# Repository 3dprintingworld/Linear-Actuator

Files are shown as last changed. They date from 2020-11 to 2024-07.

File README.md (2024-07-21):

# Mostly Printed Linear Actuator Project

The goal of this project is to design a mostly printed bearing that can be used on a Mostly Printed 3D printer.

### Design Level #1
PTFE Inserted Bearing<br/>
This version uses PTFE Tube otherwise known as Bowden tube as a bearing surface.  It worked good in initial testing but failed quickly after adding a load to the bearing. <br/>
(obsoleted)<br/>
<br/>

### Design Level #2<br/>
Dovetail Guided Actuator<br/>
This version utilizes a nylon filament from Jabil with a low friction addative.<br/>
(current model)<br/>
<br/>
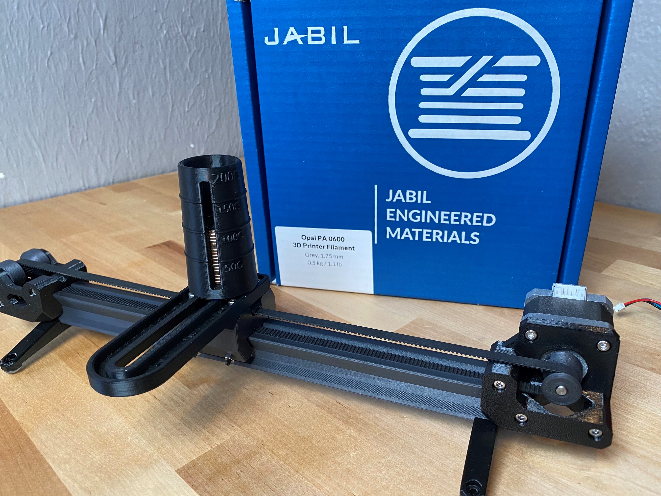
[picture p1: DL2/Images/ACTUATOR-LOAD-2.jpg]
P


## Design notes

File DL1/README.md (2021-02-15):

# Mostly printed Linear Actuator with PTFE bearing
Make a linear actuator with only a few purchased components and your 3D printer! Perfect for low load, low cycle applications. All you need is a 3D printer, stepper motor, bearing balls, fasteners, and PTFE bowden tubing.
<br/>
### Features:
PTFE inserted linear bearing<br/>
Rails can be bolted together for infinite travel lengths.<br/>
Printable TPU GT2 belt file included, prints in vase mode. It is also compatible with a standard GT2 6mm wide belt.<br/>
3D Printed idler pulley with integrated caged bearing balls.<br/>
<br/>
P
P
P
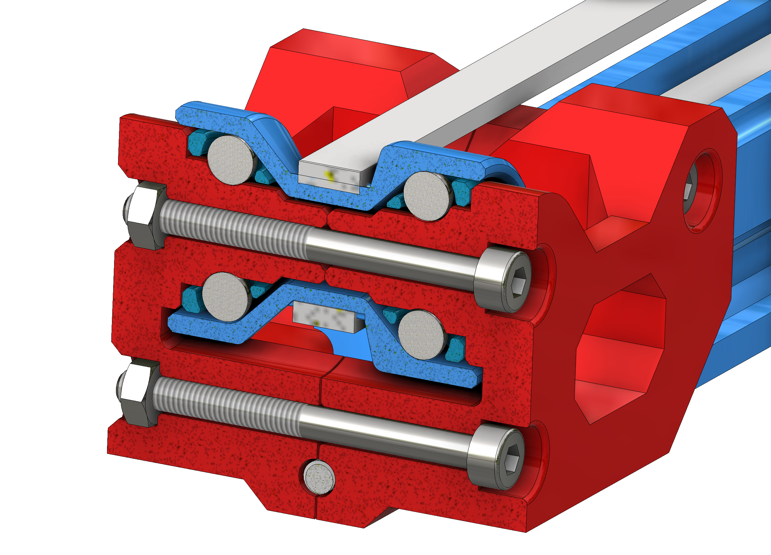
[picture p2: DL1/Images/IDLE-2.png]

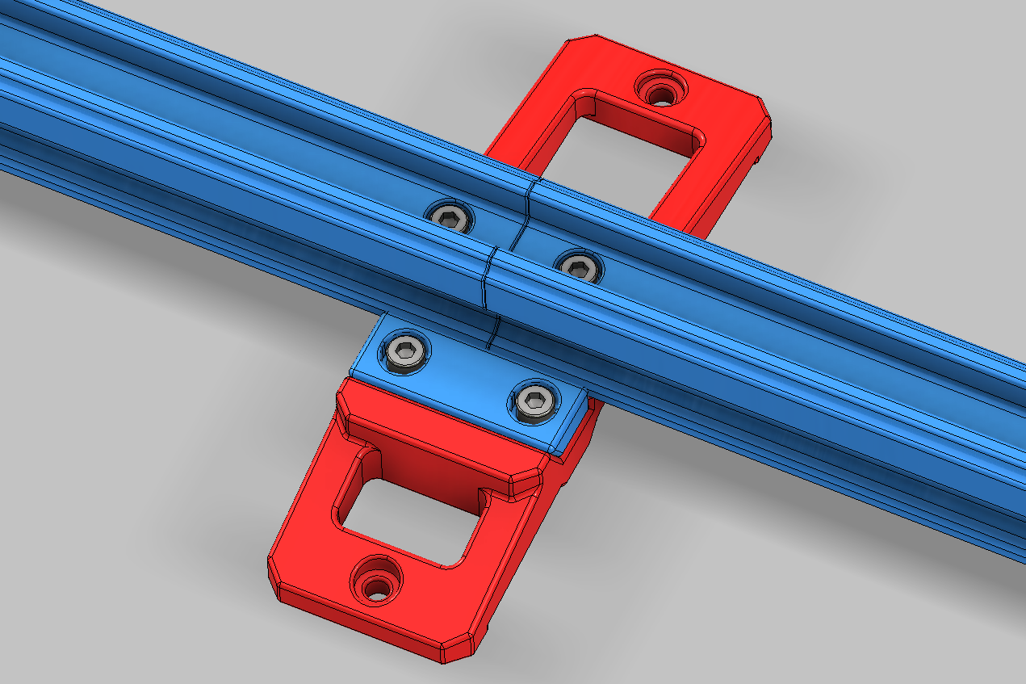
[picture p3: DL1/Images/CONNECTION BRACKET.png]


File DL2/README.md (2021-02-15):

# Mostly printed Linear Dovetail Actuator 
Make a linear actuator with only a few purchased components and your 3D printer! Perfect for low load, low cycle applications. All you need is a 3D printer, a stepper motor, bearing balls, fasteners, and PTFE bowden tubing.<br/>
### Features
This actuator is designed to use Jabil's Opal PA 0600 low friction nylon filament as bearing materail.<br/>
Printable TPU GT2 belt file included, prints in vase mode. It is also compatible with a standard GT2 6mm wide belt.<br/>
3D Printed idler pulley with integrated caged bearing balls.<br/>
<br/>
Note: Scale the parts that you print out of this filament up by 2%.<br/>
<br/>
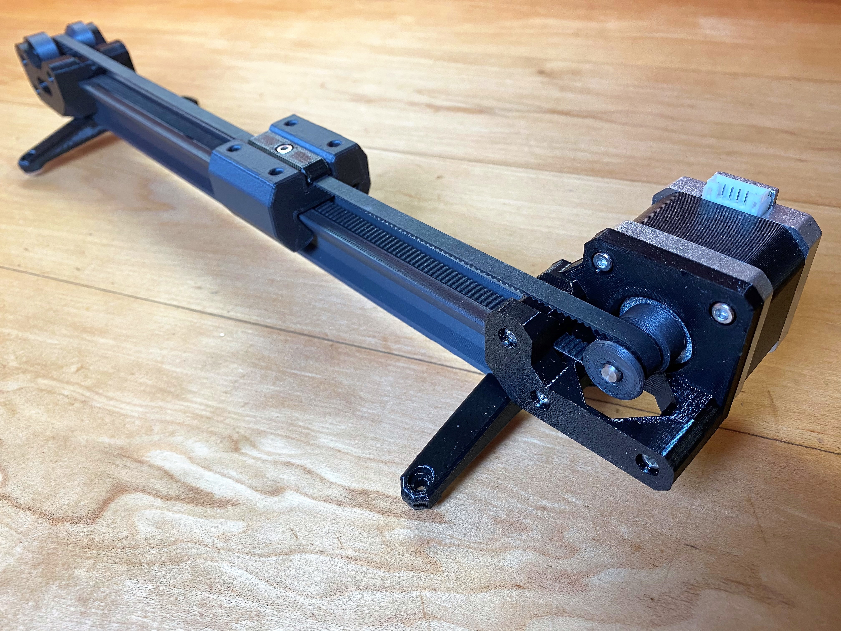
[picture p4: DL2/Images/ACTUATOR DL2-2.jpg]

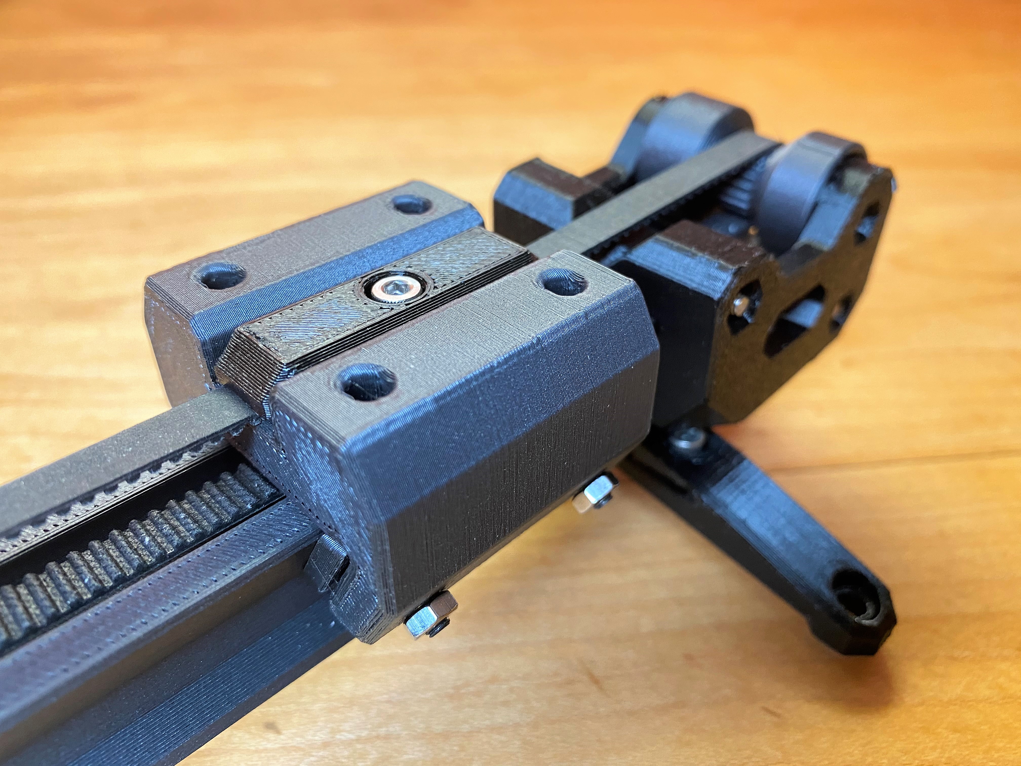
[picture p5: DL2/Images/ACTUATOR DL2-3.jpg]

P
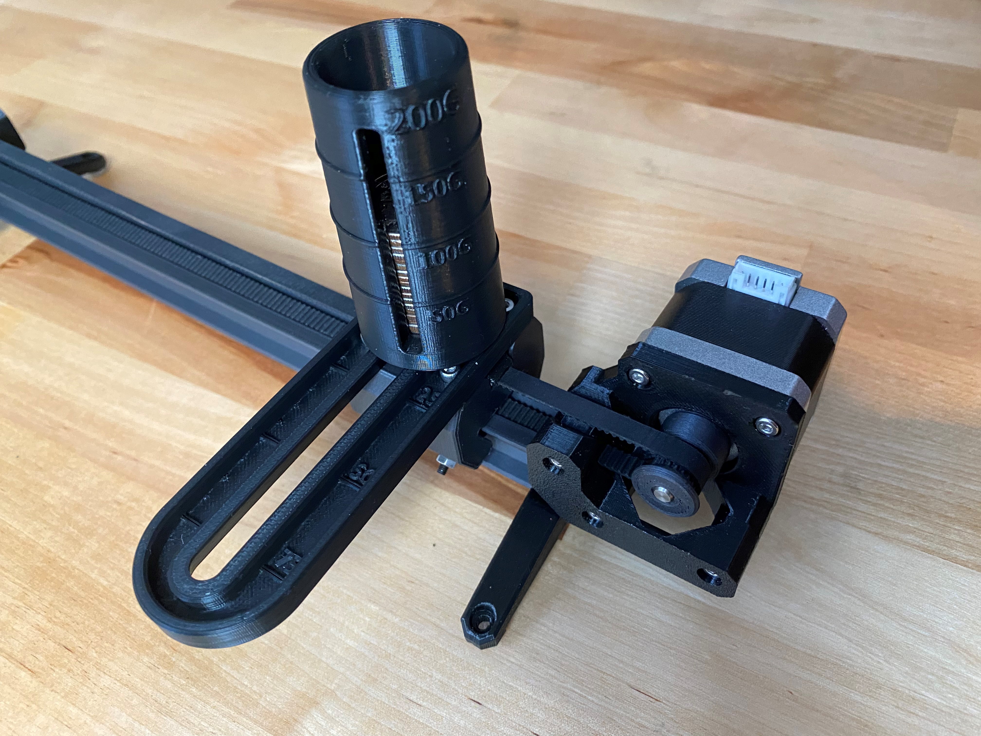
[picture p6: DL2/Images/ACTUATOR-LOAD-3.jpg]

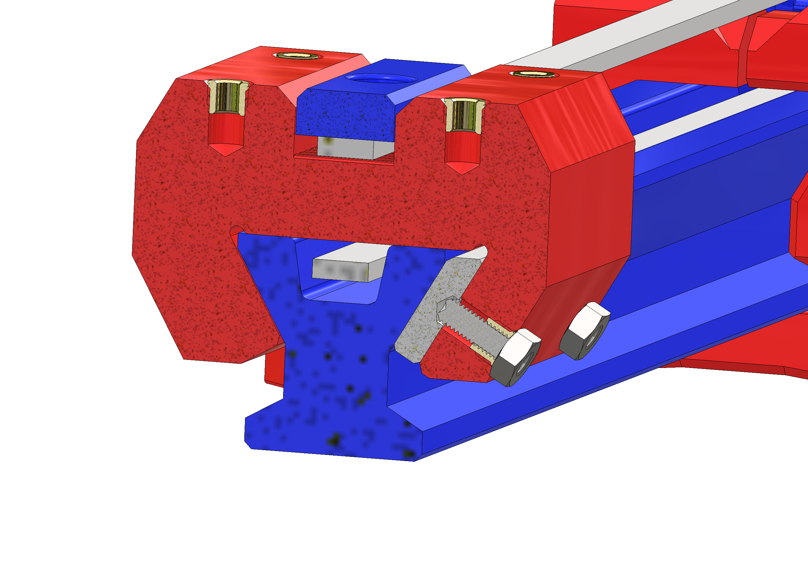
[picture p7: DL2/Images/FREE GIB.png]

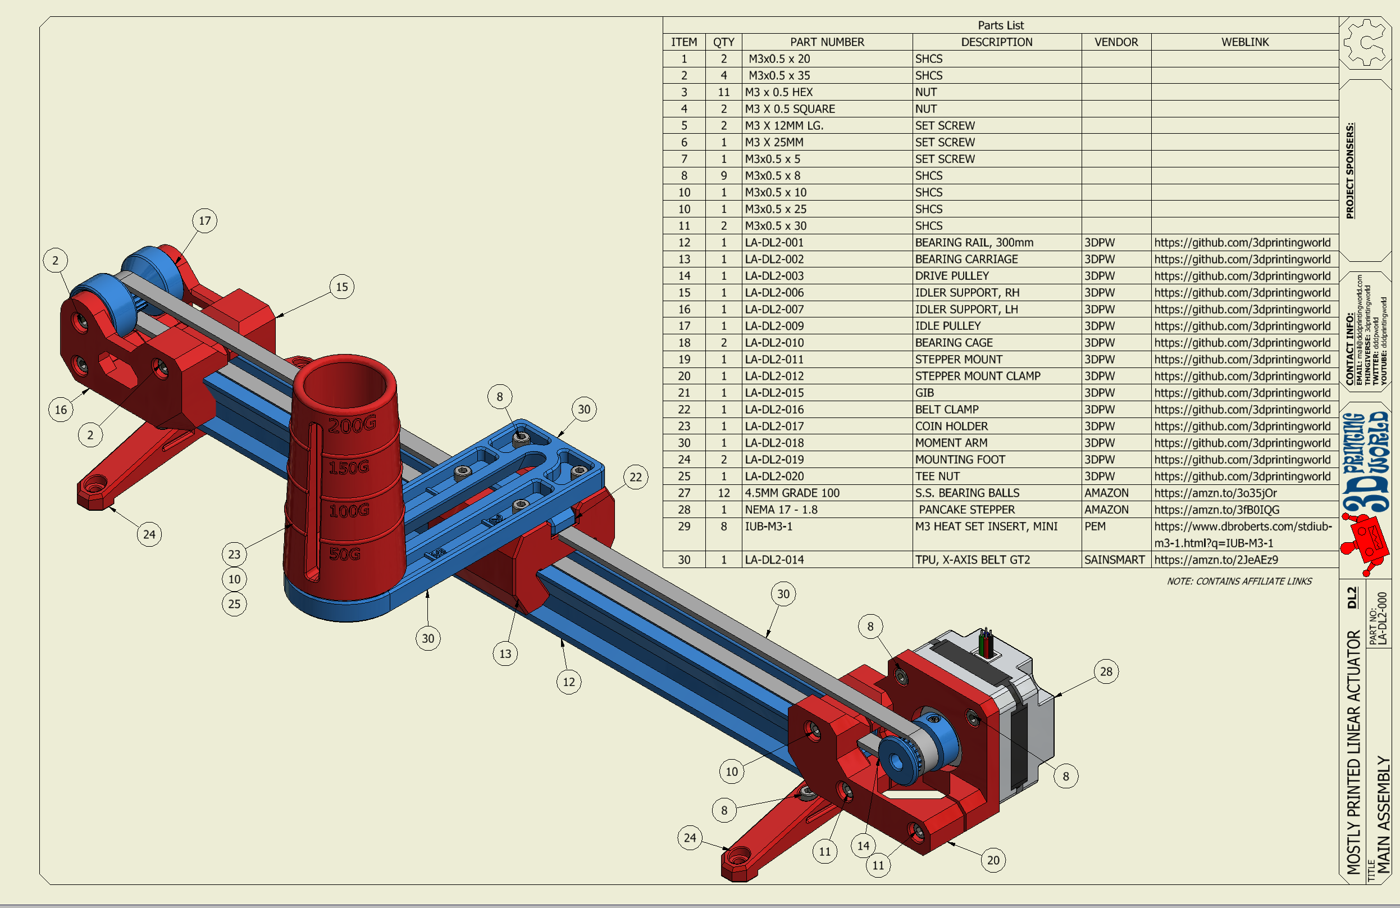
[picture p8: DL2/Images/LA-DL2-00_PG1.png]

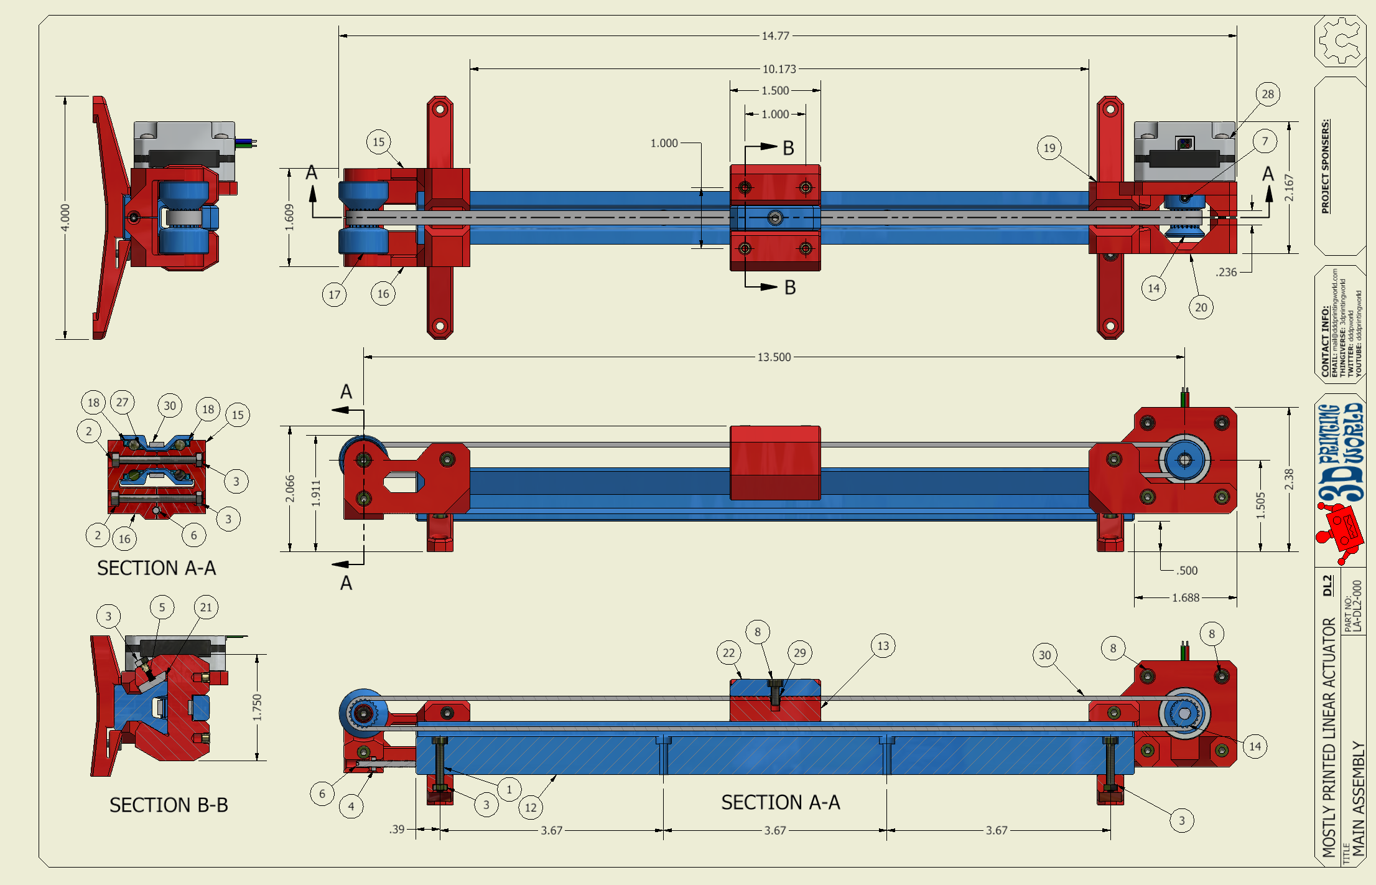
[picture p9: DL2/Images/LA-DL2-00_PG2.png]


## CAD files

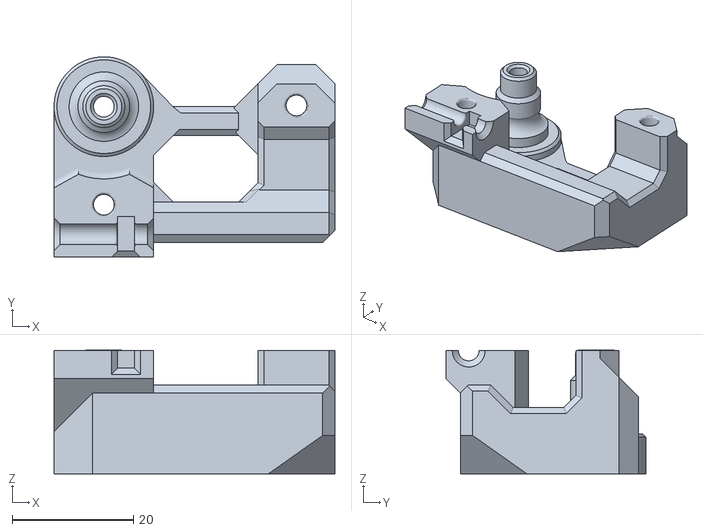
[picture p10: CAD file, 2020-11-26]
DL1/STL/LA-006.stl
46.3 x 33.0 x 20.4

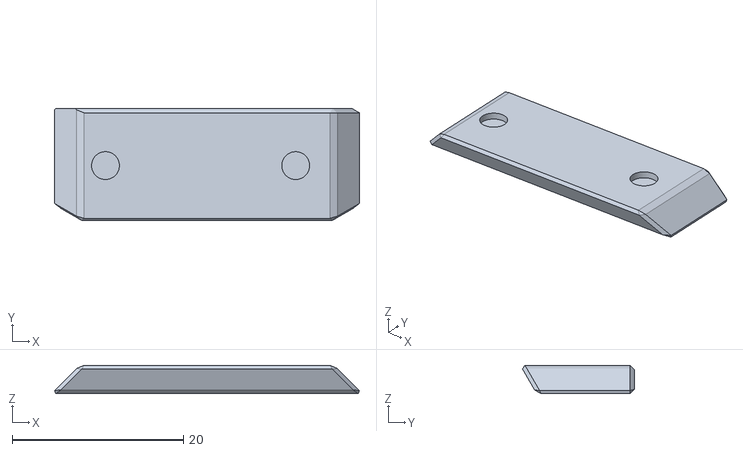
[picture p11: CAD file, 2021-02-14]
DL2/STL's/LA-DL2-015.stl
35.6 x 13.1 x 3.31

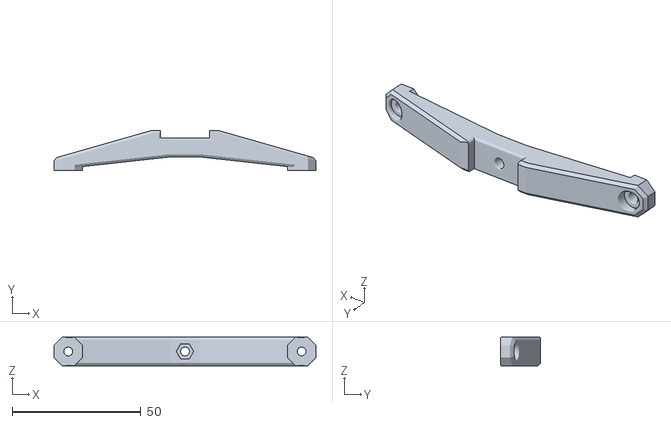
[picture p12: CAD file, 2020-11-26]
DL1/STL/LA-013.stl
101.6 x 15.6 x 11.1

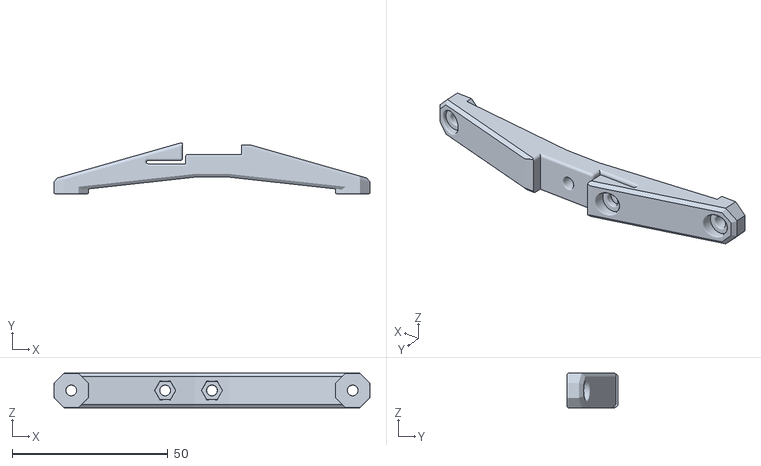
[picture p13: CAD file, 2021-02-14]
DL2/STL's/LA-DL2-019.stl
101.6 x 16.3 x 11.1

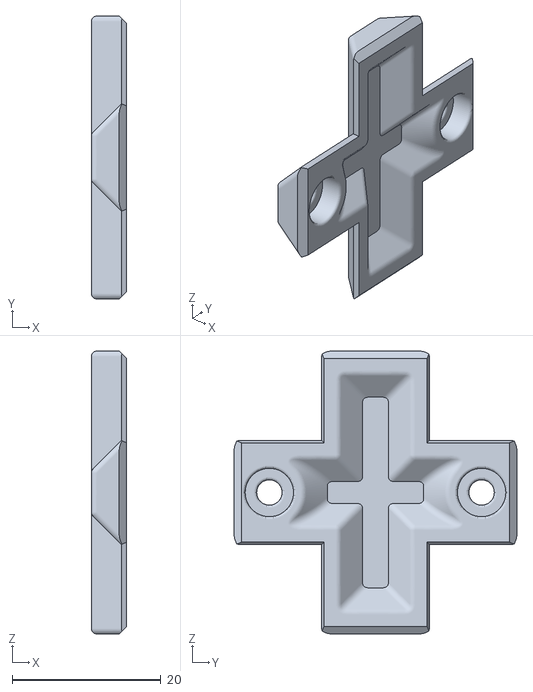
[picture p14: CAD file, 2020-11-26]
DL1/STL/LA-005.stl
4.76 x 38.1 x 38.1

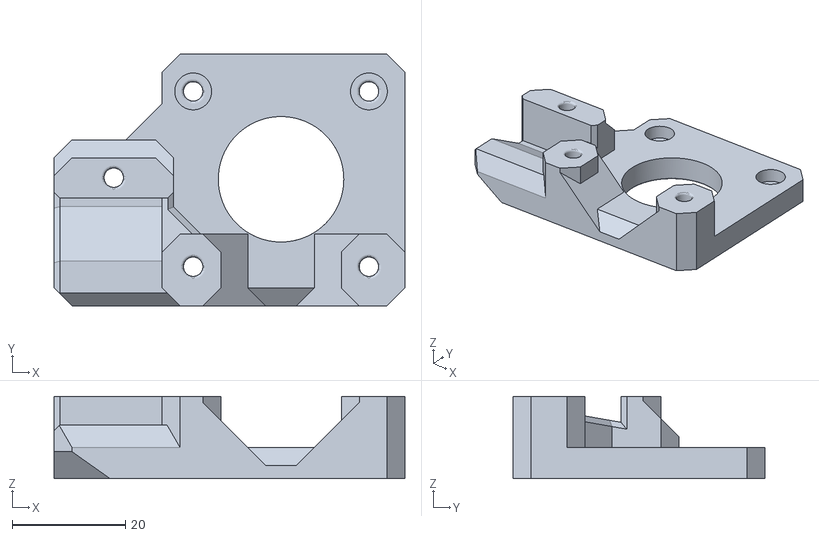
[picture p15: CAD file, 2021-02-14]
DL2/STL's/LA-DL2-011.stl
61.9 x 44.4 x 14.5

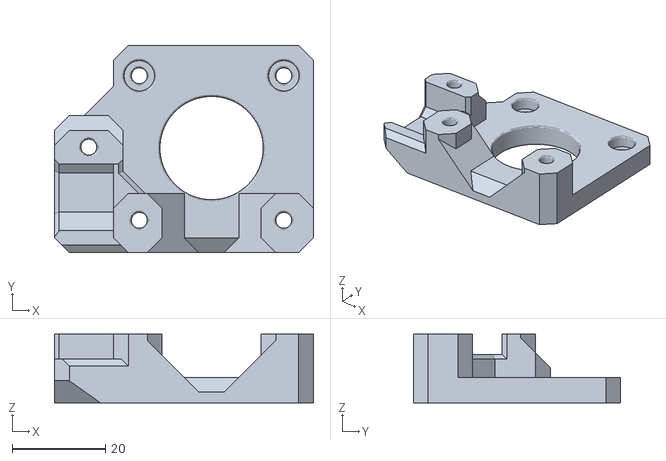
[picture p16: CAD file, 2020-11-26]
DL1/STL/LA-011.stl
55.6 x 44.4 x 14.8

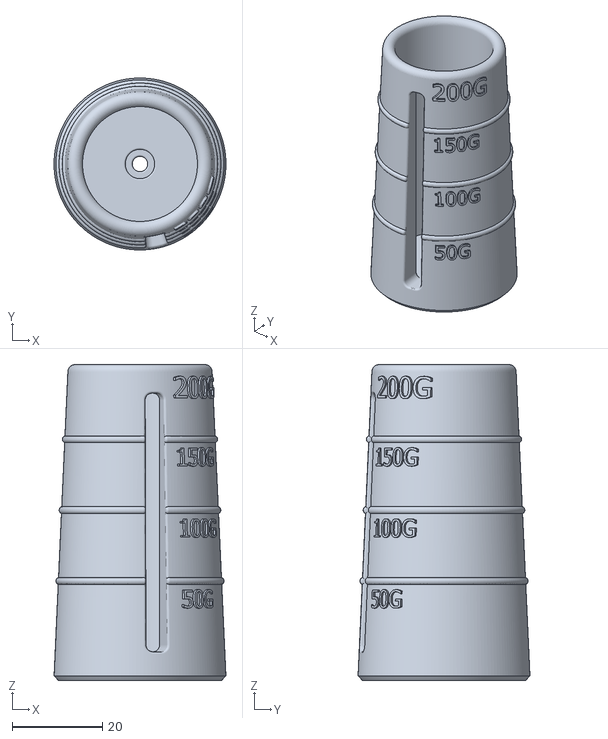
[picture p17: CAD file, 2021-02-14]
DL2/STL's/LA-DL2-017.stl
38.0 x 38.0 x 69.8

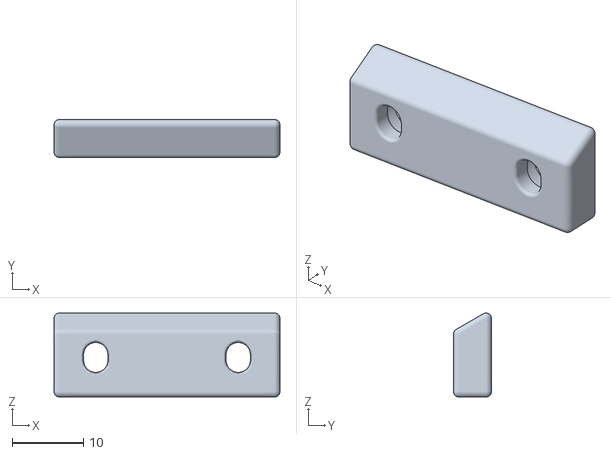
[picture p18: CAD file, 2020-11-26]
DL1/STL/LA-016.stl
31.8 x 5.33 x 11.8

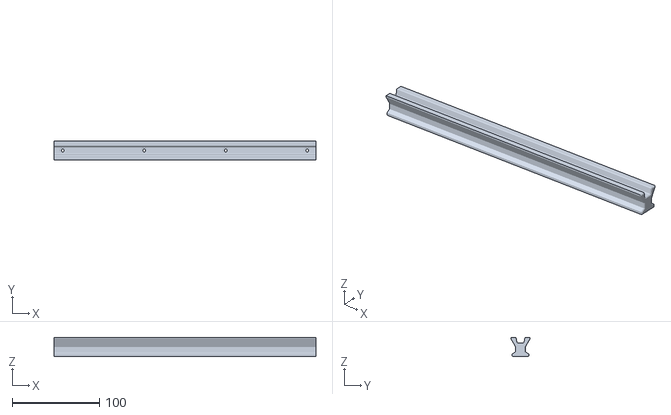
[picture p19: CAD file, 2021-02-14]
DL2/STL's/LA-DL2-001.stl
300.0 x 22.2 x 22.2

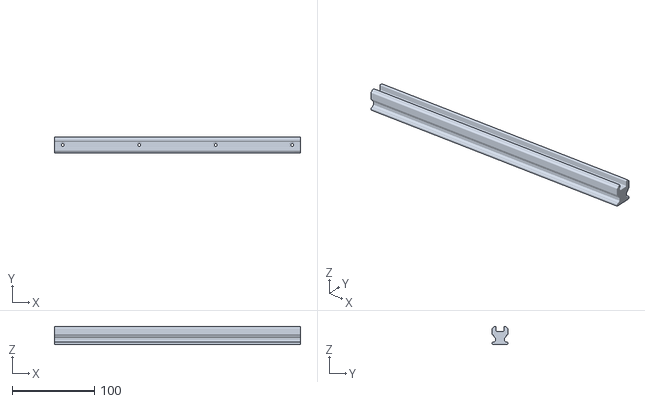
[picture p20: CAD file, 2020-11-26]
DL1/STL/LA-001.stl
300.0 x 19.1 x 22.2

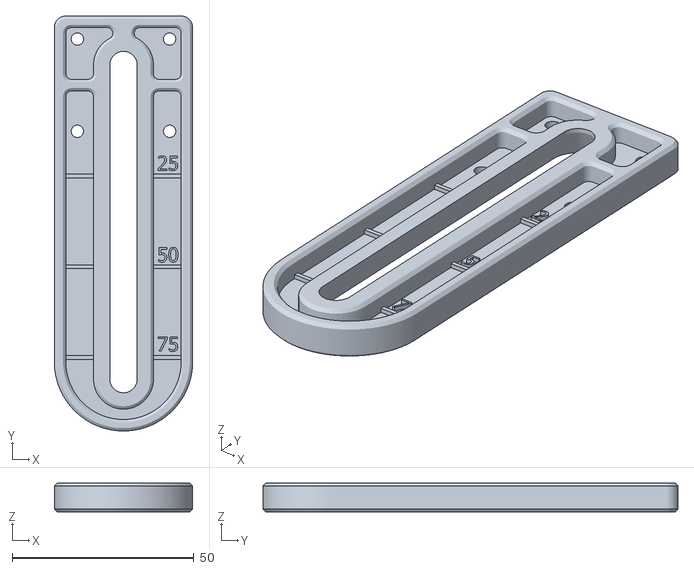
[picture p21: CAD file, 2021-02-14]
DL2/STL's/LA-DL2-018.stl
38.1 x 114.3 x 7.94

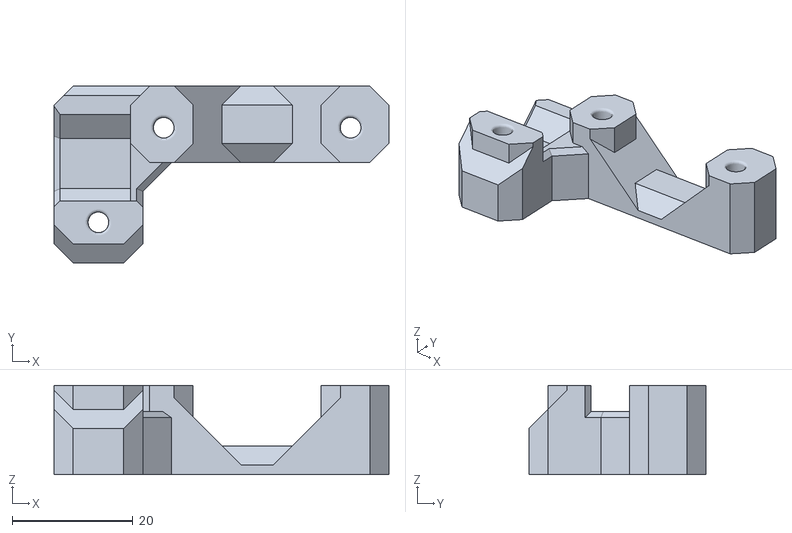
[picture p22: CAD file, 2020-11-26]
DL1/STL/LA-012.stl
55.6 x 29.4 x 14.8

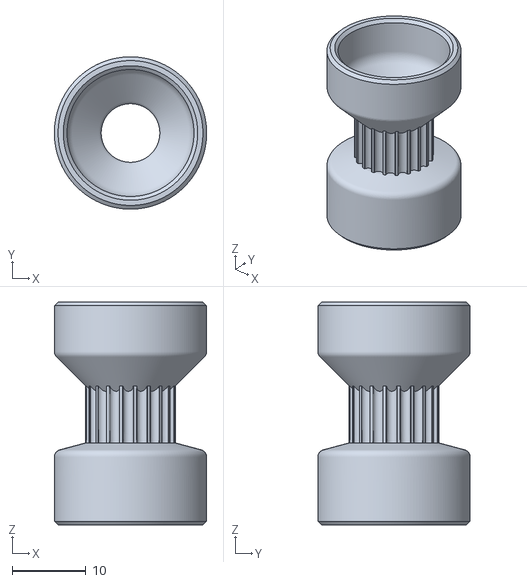
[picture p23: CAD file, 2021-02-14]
DL2/STL's/LA-DL2-009.stl
20.6 x 20.6 x 30.2

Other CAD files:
DL1/STL/LA-007.stl
DL2/STL's/LA-DL2-012.stl
DL1/STL/LA-002.stl
DL2/STL's/LA-DL2-006.stl
DL1/STL/LA-003.stl
DL1/STL/LA-009.stl
DL1/STL/LA-015.stl
DL2/STL's/LA-DL2-002.stl
DL2/STL's/LA-DL2-003.stl
DL2/STL's/LA-DL2-007.stl
DL2/STL's/LA-DL2-016.stl
DL2/STL's/LA-DL2-020.stl

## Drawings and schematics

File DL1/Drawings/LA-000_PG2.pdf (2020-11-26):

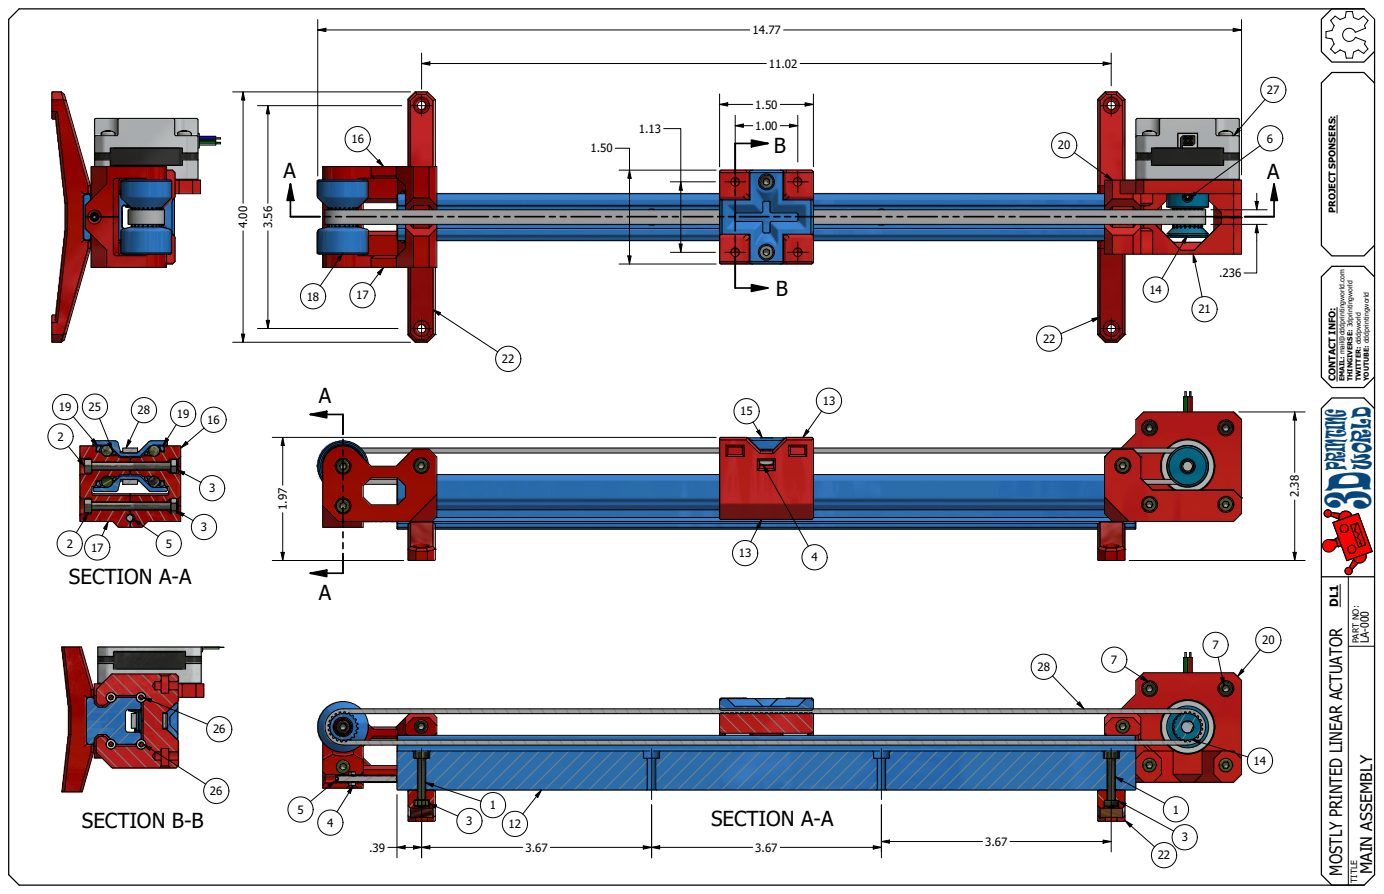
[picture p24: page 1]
PART NO:; MAIN ASSEMBLY; DL1 PROJECT SPONSERS:

MOSTLY PRINTED LINEAR ACTUATOR 3DPRINTING WORLD CONTACT INFO: EMAIL: mail@dddprintingworld.com THINGIVERSE: 3dprintingworld TWITTER: dddpworld YOUTUBE: dddprintingworld

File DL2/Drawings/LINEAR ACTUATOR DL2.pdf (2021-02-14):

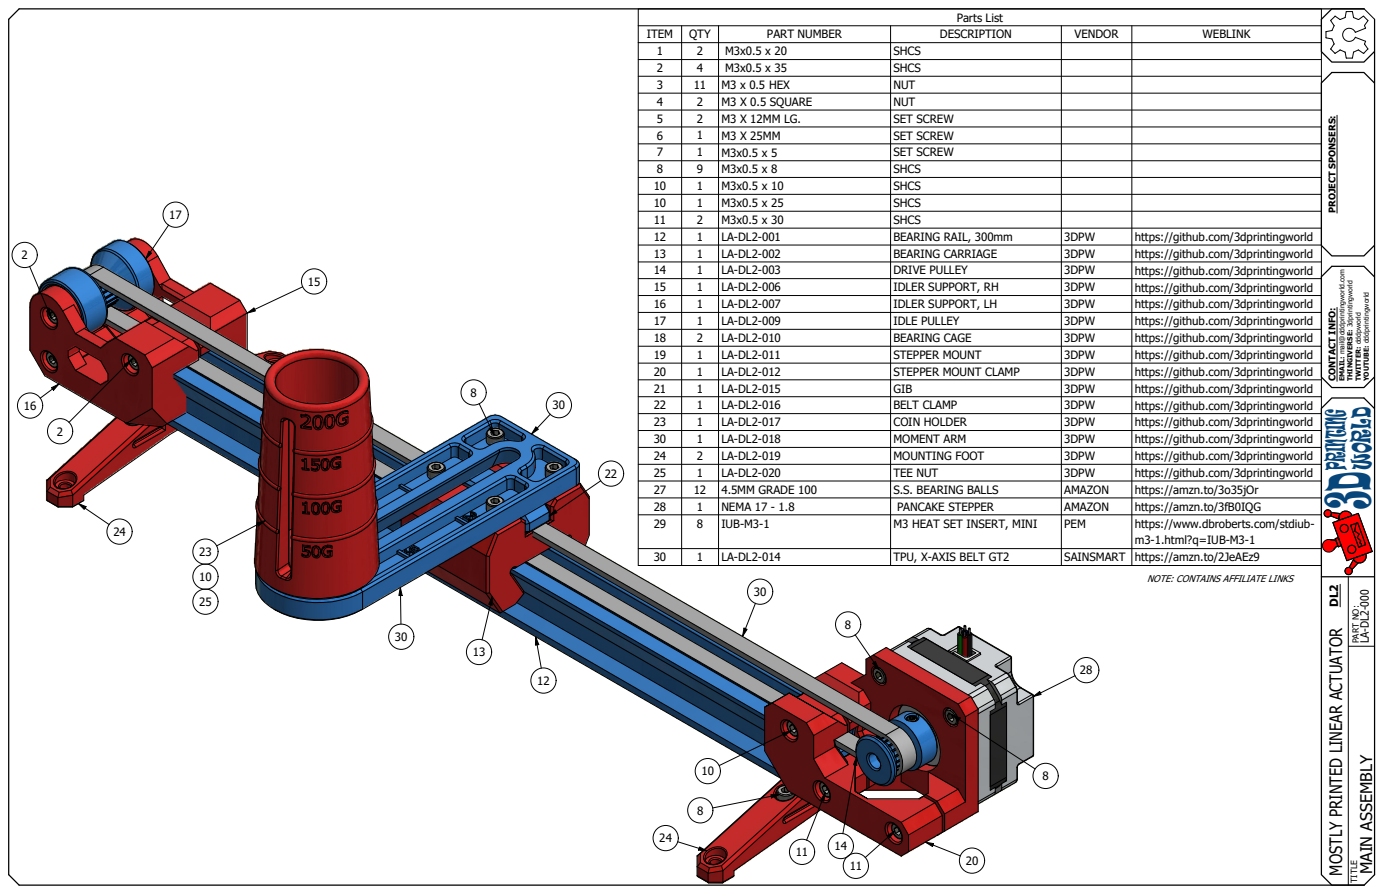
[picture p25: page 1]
PART NO:; MAIN ASSEMBLY; DL2 PROJECT SPONSERS:

I T E M | Q T Y | P A RT N U M B E R | D E S C R I P T I O N | V E N D O R | W E B L I N K
1 | 2 | M 3 x 0 . 5 x 2 0 | S H C S
2 | 4 | M 3 x 0 . 5 x 3 5 | S H C S
3 | 1 1 | M 3 x 0 . 5 H E X | N U T
4 | 2 | M 3 X 0 . 5 S Q U A R E | N U T
5 | 2 | M 3 X 1 2 M M L G . | S E T S C R E W
6 | 1 | M 3 X 2 5 M M | S E T S C R E W
7 | 1 | M 3 x 0 . 5 x 5 | S E T S C R E W
8 | 9 | M 3 x 0 . 5 x 8 | S H C S
1 0 | 1 | M 3 x 0 . 5 x 1 0 | S H C S
1 0 | 1 | M 3 x 0 . 5 x 2 5 | S H C S
1 1 | 2 | M 3 x 0 . 5 x 3 0 | S H C S
1 2 | 1 | LA -D L 2 -0 0 1 | B E A R I N G RA I L , 3 0 0 m m | 3 D P W | h t t p s : / / g i t h u b . c o m / 3 d p r i n t i n g w o rld
1 3 | 1 | LA -D L 2 -0 0 2 | B E A R I N G C A R R I A G E | 3 D P W | h t t p s : / / g i t h u b . c o m / 3 d p r i n t i n g w o rld
1 4 | 1 | LA -D L 2 -0 0 3 | D R I V E P U L L E Y | 3 D P W | h t t p s : / / g i t h u b . c o m / 3 d p r i n t i n g w o rld
1 5 | 1 | LA -D L 2 -0 0 6 | I D L E R S U P P O RT , R H | 3 D P W | h t t p s : / / g i t h u b . c o m / 3 d p r i n t i n g w o rld
1 6 | 1 | LA -D L 2 -0 0 7 | I D L E R S U P P O RT , L H | 3 D P W | h t t p s : / / g i t h u b . c o m / 3 d p r i n t i n g w o rld
1 7 | 1 | LA -D L 2 -0 0 9 | I D L E P U L L E Y | 3 D P W | h t t p s : / / g i t h u b . c o m / 3 d p r i n t i n g w o rld
1 8 | 2 | LA -D L 2 -0 1 0 | B E A R I N G C A G E | 3 D P W | h t t p s : / / g i t h u b . c o m / 3 d p r i n t i n g w o rld
1 9 | 1 | LA -D L 2 -0 1 1 | S T E P P E R M O U N T | 3 D P W | h t t p s : / / g i t h u b . c o m / 3 d p r i n t i n g w o rld
2 0 | 1 | LA -D L 2 -0 1 2 | S T E P P E R M O U N T C LA M P | 3 D P W | h t t p s : / / g i t h u b . c o m / 3 d p r i n t i n g w o rld
2 1 | 1 | LA -D L 2 -0 1 5 | G I B | 3 D P W | h t t p s : / / g i t h u b . c o m / 3 d p r i n t i n g w o rld
2 2 | 1 | LA -D L 2 -0 1 6 | B E LT C LA M P | 3 D P W | h t t p s : / / g i t h u b . c o m / 3 d p r i n t i n g w o rld
2 3 | 1 | LA -D L 2 -0 1 7 | C O I N H O L D E R | 3 D P W | h t t p s : / / g i t h u b . c o m / 3 d p r i n t i n g w o rld
3 0 | 1 | LA -D L 2 -0 1 8 | M O M E N T A R M | 3 D P W | h t t p s : / / g i t h u b . c o m / 3 d p r i n t i n g w o rld
2 4 | 2 | LA -D L 2 -0 1 9 | M O U N T I N G F O O T | 3 D P W | h t t p s : / / g i t h u b . c o m / 3 d p r i n t i n g w o rld
2 5 | 1 | LA -D L 2 -0 2 0 | T E E N U T | 3 D P W | h t t p s : / / g i t h u b . c o m / 3 d p r i n t i n g w o rld
2 7 | 1 2 | 4 . 5 M M G RA D E 1 0 0 | S . S . B E A R I N G B A L L S | A M A Z O N | h t t p s : / / a m z n . t o / 3 o 3 5 j O r
2 8 | 1 | N E M A 1 7 -1 . 8 | P A N C A K E S T E P P E R | A M A Z O N | h t t p s : / / a m z n . t o / 3 f B 0 I Q G
2 9 | 8 | I U B -M 3 -1 | M 3 H E AT S E T I N S E RT , M I N I | P E M | h t t p s : / / w w w . d b r o b e r t s . c o m / s t d i u b -m 3 -1 . h t ml? q = I U B -M 3 -1

MOSTLY PRINTED LINEAR ACTUATOR 3DPRINTING WORLD CONTACT INFO: EMAIL: mail@dddprintingworld.com THINGIVERSE: 3dprintingworld TWITTER: dddpworld YOUTUBE: dddprintingworld

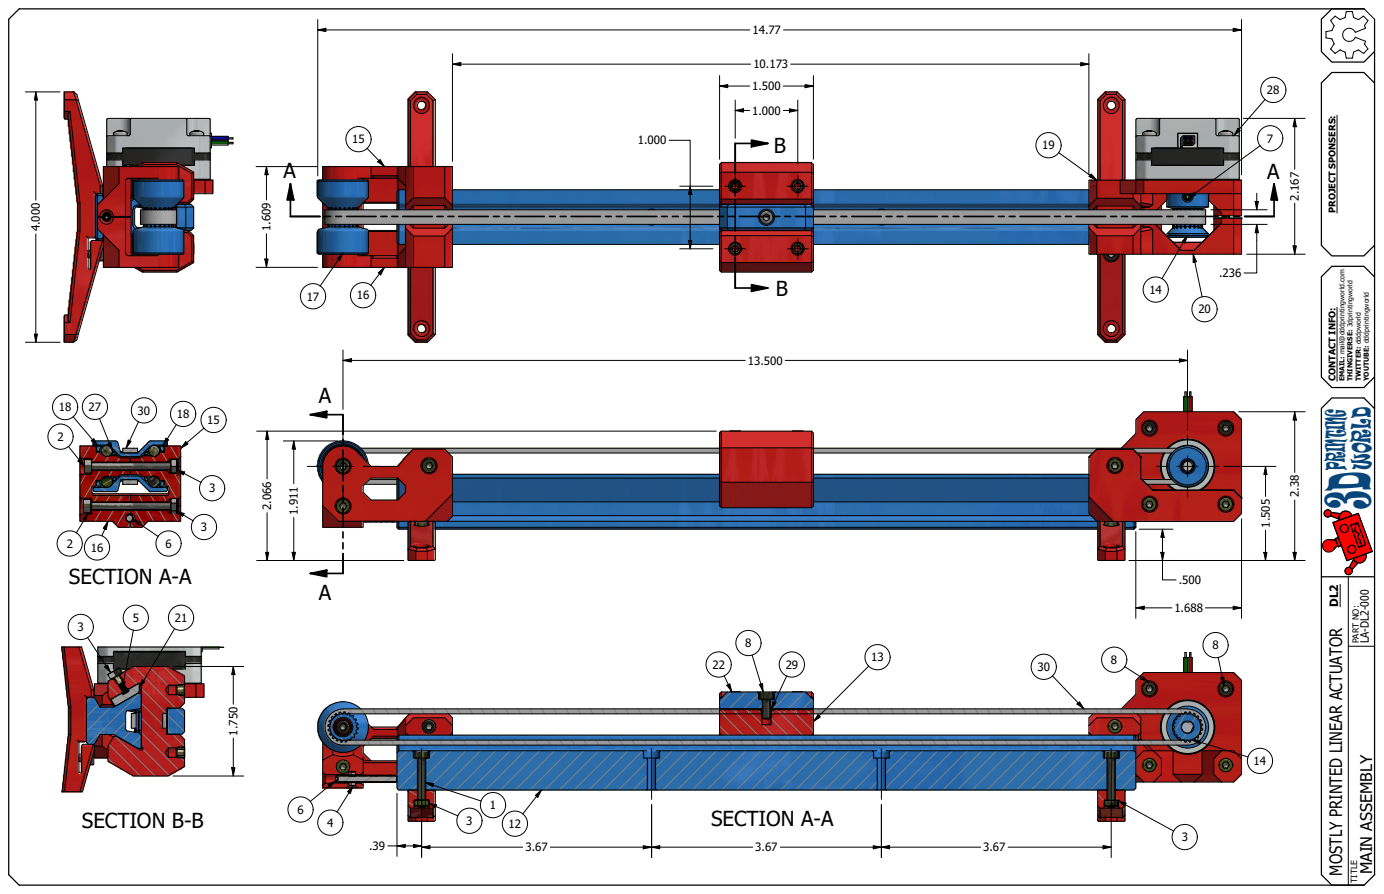
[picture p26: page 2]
PART NO:; MAIN ASSEMBLY; DL2 PROJECT SPONSERS:

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

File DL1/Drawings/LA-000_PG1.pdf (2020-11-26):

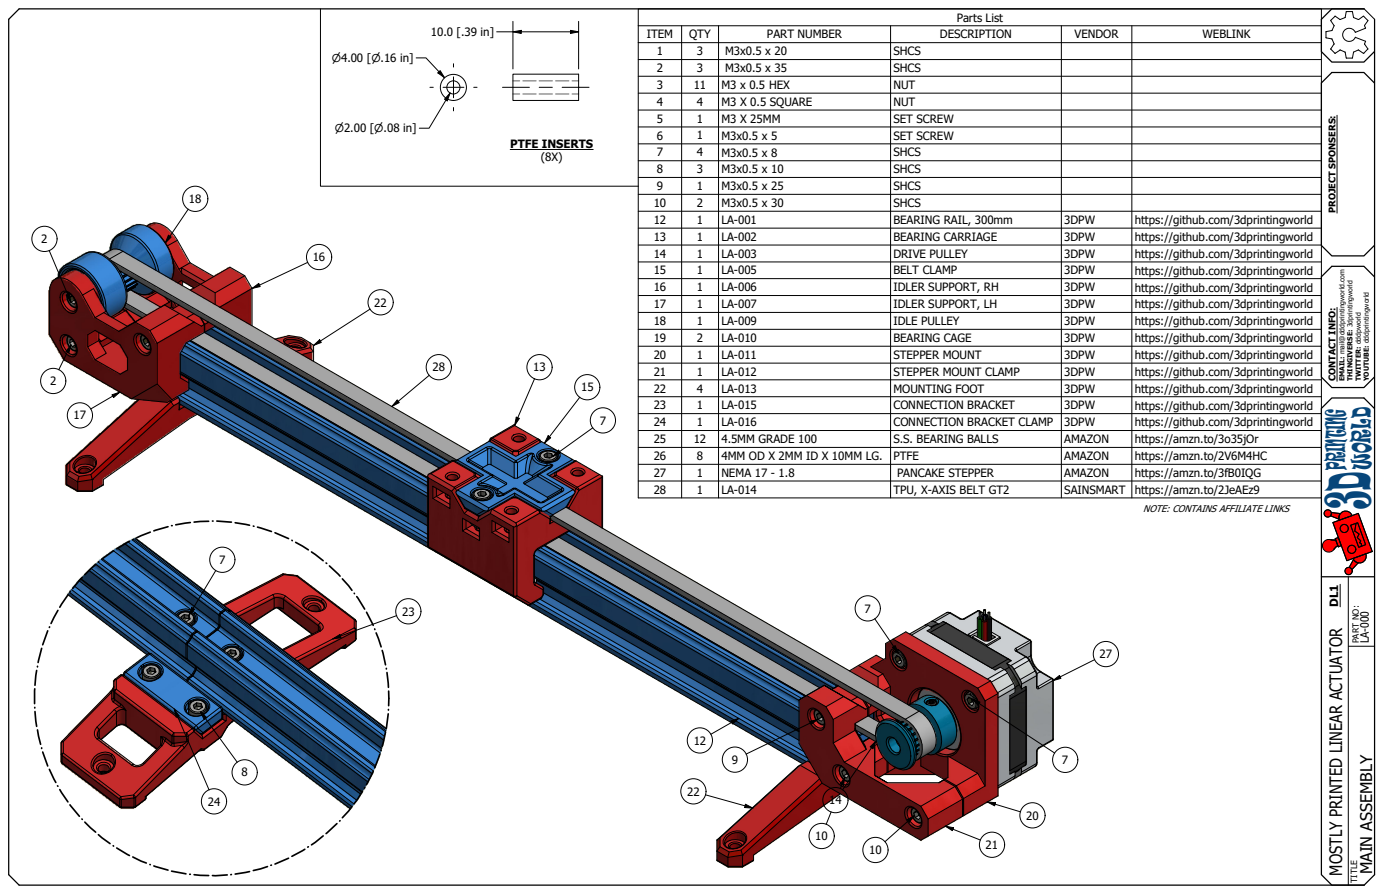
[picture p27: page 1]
PART NO:; MAIN ASSEMBLY; DL1 PROJECT SPONSERS:

I T E M | Q T Y | P A RT N U M B E R | D E S C R I P T I O N | V E N D O R | W E B L I N K
1 | 3 | M 3 x 0 . 5 x 2 0 | S H C S
2 | 3 | M 3 x 0 . 5 x 3 5 | S H C S
3 | 1 1 | M 3 x 0 . 5 H E X | N U T
4 | 4 | M 3 X 0 . 5 S Q U A R E | N U T
5 | 1 | M 3 X 2 5 M M | S E T S C R E W
6 | 1 | M 3 x 0 . 5 x 5 | S E T S C R E W

7 | 4 | M 3 x 0 . 5 x 8 | S H C S
8 | 3 | M 3 x 0 . 5 x 1 0 | S H C S

1 0 | 2 | M 3 x 0 . 5 x 3 0 | S H C S
1 2 | 1 | LA -0 0 1 | B E A R I N G RA I L , 3 0 0 m m | 3 D P W | h t t p s : / / g i t h u b . c o m / 3 d p r i n t i n g w o rld
1 3 | 1 | LA -0 0 2 | B E A R I N G C A R R I A G E | 3 D P W | h t t p s : / / g i t h u b . c o m / 3 d p r i n t i n g w o rld
1 4 | 1 | LA -0 0 3 | D R I V E P U L L E Y | 3 D P W | h t t p s : / / g i t h u b . c o m / 3 d p r i n t i n g w o rld
1 5 | 1 | LA -0 0 5 | B E LT C LA M P | 3 D P W | h t t p s : / / g i t h u b . c o m / 3 d p r i n t i n g w o rld
1 6 | 1 | LA -0 0 6 | I D L E R S U P P O RT , R H | 3 D P W | h t t p s : / / g i t h u b . c o m / 3 d p r i n t i n g w o rld
1 7 | 1 | LA -0 0 7 | I D L E R S U P P O RT , L H | 3 D P W | h t t p s : / / g i t h u b . c o m / 3 d p r i n t i n g w o rld
1 8 | 1 | LA -0 0 9 | I D L E P U L L E Y | 3 D P W | h t t p s : / / g i t h u b . c o m / 3 d p r i n t i n g w o rld
1 9 | 2 | LA -0 1 0 | B E A R I N G C A G E | 3 D P W | h t t p s : / / g i t h u b . c o m / 3 d p r i n t i n g w o rld
2 0 | 1 | LA -0 1 1 | S T E P P E R M O U N T | 3 D P W | h t t p s : / / g i t h u b . c o m / 3 d p r i n t i n g w o rld
2 1 | 1 | LA -0 1 2 | S T E P P E R M O U N T C LA M P | 3 D P W | h t t p s : / / g i t h u b . c o m / 3 d p r i n t i n g w o rld
2 2 | 4 | LA -0 1 3 | M O U N T I N G F O O T | 3 D P W | h t t p s : / / g i t h u b . c o m / 3 d p r i n t i n g w o rld
2 3 | 1 | LA -0 1 5 | C O N N E C T I O N B RA C K E T | 3 D P W | h t t p s : / / g i t h u b . c o m / 3 d p r i n t i n g w o rld
2 4 | 1 | LA -0 1 6 | C O N N E C T I O N B RA C K E T C LA M P | 3 D P W | h t t p s : / / g i t h u b . c o m / 3 d p r i n t i n g w o rld
2 5 | 1 2 | 4 . 5 M M G RA D E 1 0 0 | S . S . B E A R I N G B A L L S | A M A Z O N | h t t p s : / / a m z n . t o / 3 o 3 5 j O r
2 6 | 8 | 4 M M O D X 2 M M I D X 1 0 M M L G . | P T F E | A M A Z O N | h t t p s : / / a m z n . t o / 2 V 6 M 4 H C
2 7 | 1 | N E M A 1 7 -1 . 8 | P A N C A K E S T E P P E R | A M A Z O N | h t t p s : / / a m z n . t o / 3 f B 0 I Q G
2 8 | 1 | LA -0 1 4 | T P U , X -AX I S B E L T G T 2 | S A I N S M A RT | h t t p s : / / a m z n . t o / 2 J e A E z 9

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
